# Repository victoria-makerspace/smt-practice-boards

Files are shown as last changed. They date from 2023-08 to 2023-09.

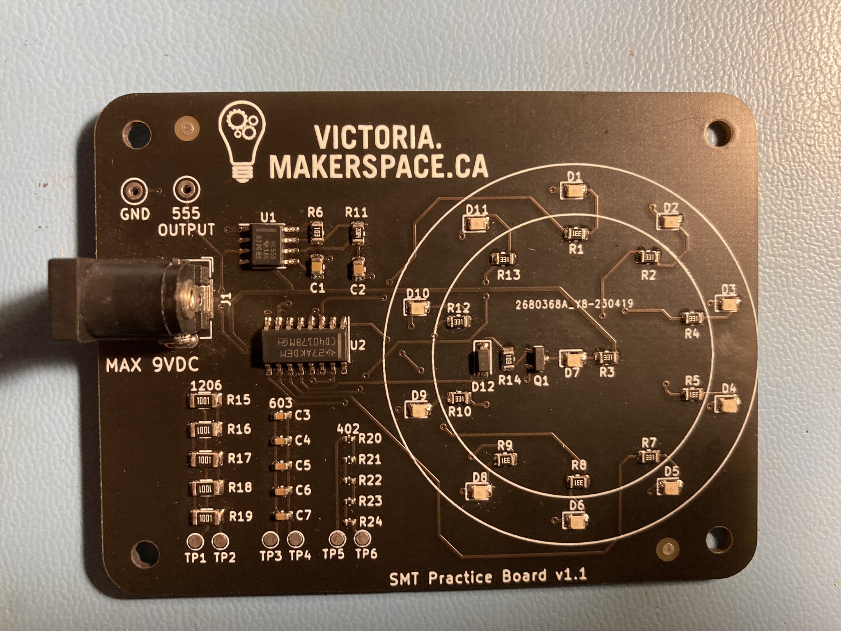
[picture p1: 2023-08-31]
board-rotating-leds/images/IMG_4738.jpeg

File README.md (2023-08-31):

# SMT Practice Boards

This repository contains Surface Mount Technology(SMT) board designs that are intended to be used for training purposes.  Every SMT practice board design provides the information:  

1. bom:  Bill of Materials, including DigiKey part references.
1. gerber: files used to order PCBs from suppliers such as PCBWay or JLCPCB.
1. images:  photos of the board
1. kicad:  KiCAD schematic and layout files.  Fiducials are included on the layouts to support automatic pick and place machines.
1. schematic:  PDF schematic 
1. stencil:  DXF and LightBurn format files used to make laser cut stencils.  Laser cut stencils can be created using 4 mil mylar. 

## Rotating LEDs Practice Board
The [Rotating LEDs practice board](https://github.com/victoria-makerspace/smt-practice-boards/tree/main/board-rotating-leds) is inspired from the [Gikfun SMT training board](https://gikfun.com/collections/frontpage/products/gikfun-diy-smd-smt-welding-practice-soldering-skill-training-board)



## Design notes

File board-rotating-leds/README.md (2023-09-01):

# Rotating LEDs Practice Board

Click on the image below to see the demo

Watch the video (https://www.youtube.com/embed/diBXtM5LNmg)

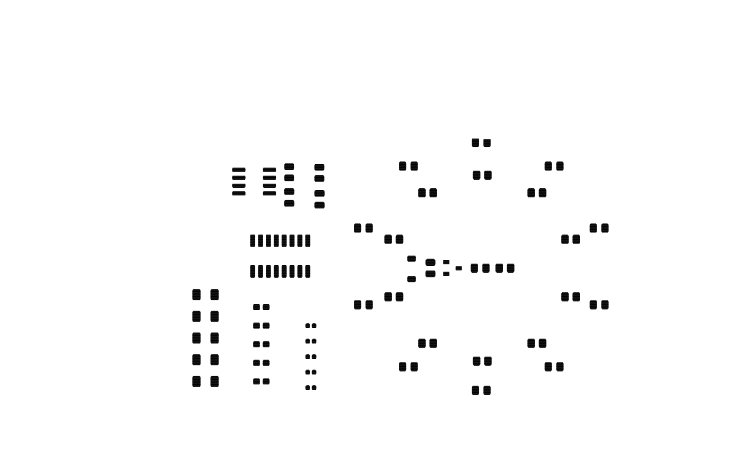
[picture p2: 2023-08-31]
board-rotating-leds/stencil/stencil-rotating-leds.png

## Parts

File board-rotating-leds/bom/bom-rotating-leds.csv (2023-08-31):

Description | Manufacturer Part Number | Digi-Key Part # | Quantity | Unit Price (USD)
DC POWER JACK, THRU HOLE, HORIZO | DCJ200-10-A-K1-K | 2073-DCJ200-10-A-K1-K-ND | 1 | $0.790
RES 330 OHM 5% 1/8W 0805 | RC0805JR-07330RL | 311-330ARCT-ND | 11 | $0.010
RES 1K OHM 1% 1/16W 0402 | WR04X1001FTL | 1292-WR04X1001FTLCT-ND | 5 | $0.004
TRANSISTOR, 25V 300MW 500MA 150MHZ 600MV@500 | S8050 | 4518-S8050CT-ND | 1 | $0.230
RES 2M OHM 1% 1/8W 0805 | RC0805FR-072ML | 311-2.00MCRCT-ND | 1 | $0.040
IC DECADE COUNTER 10-BIT 16SOIC | CD4017BM96 | 296-25940-1-ND | 1 | $0.630
RES 10K OHM 5% 1/8W 0805 | RC0805JR-0710KL | 311-10KARCT-ND | 2 | $0.030
DIODE GEN PURP 100V 150MA SOD123 | 1N4148W-TP | 1N4148WTPMSCT-ND | 1 | $0.100
RES 1K OHM 1% 1/2W 1206 | RNCP1206FTD1K00 | RNCP1206FTD1K00CT-ND | 5 | $0.090
IC OSC SGL TIMER 100KHZ 8-SOIC | NE555DR | 296-6501-1-ND | 1 | $0.520
RED LED, 2.0(L)X1.3(W)X0.8(H) MM | B1701USD-20D000114U1930 | 3147-B1701USD-20D000114U1930CT-ND | 10 | $0.100
BLUE LED, 2.0(L)X1.3(W)X0.8(H) MM | B1701NB--20D000114U1930 | 3147-B1701NB--20D000114U1930CT-ND | 1 | $0.110
CAP CER 0.1UF 50V X7R 0603 | C0603C104M5RAC7867 | 399-C0603C104M5RAC7867CT-ND | 5 | $0.010
CAP CER 0.1UF 50V X7R 0805 | C0805C104M5RAC7800 | 399-C0805C104M5RAC7800CT-ND | 2 | $0.070

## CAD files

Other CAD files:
board-rotating-leds/stencil/stencil-rotating-leds.dxf

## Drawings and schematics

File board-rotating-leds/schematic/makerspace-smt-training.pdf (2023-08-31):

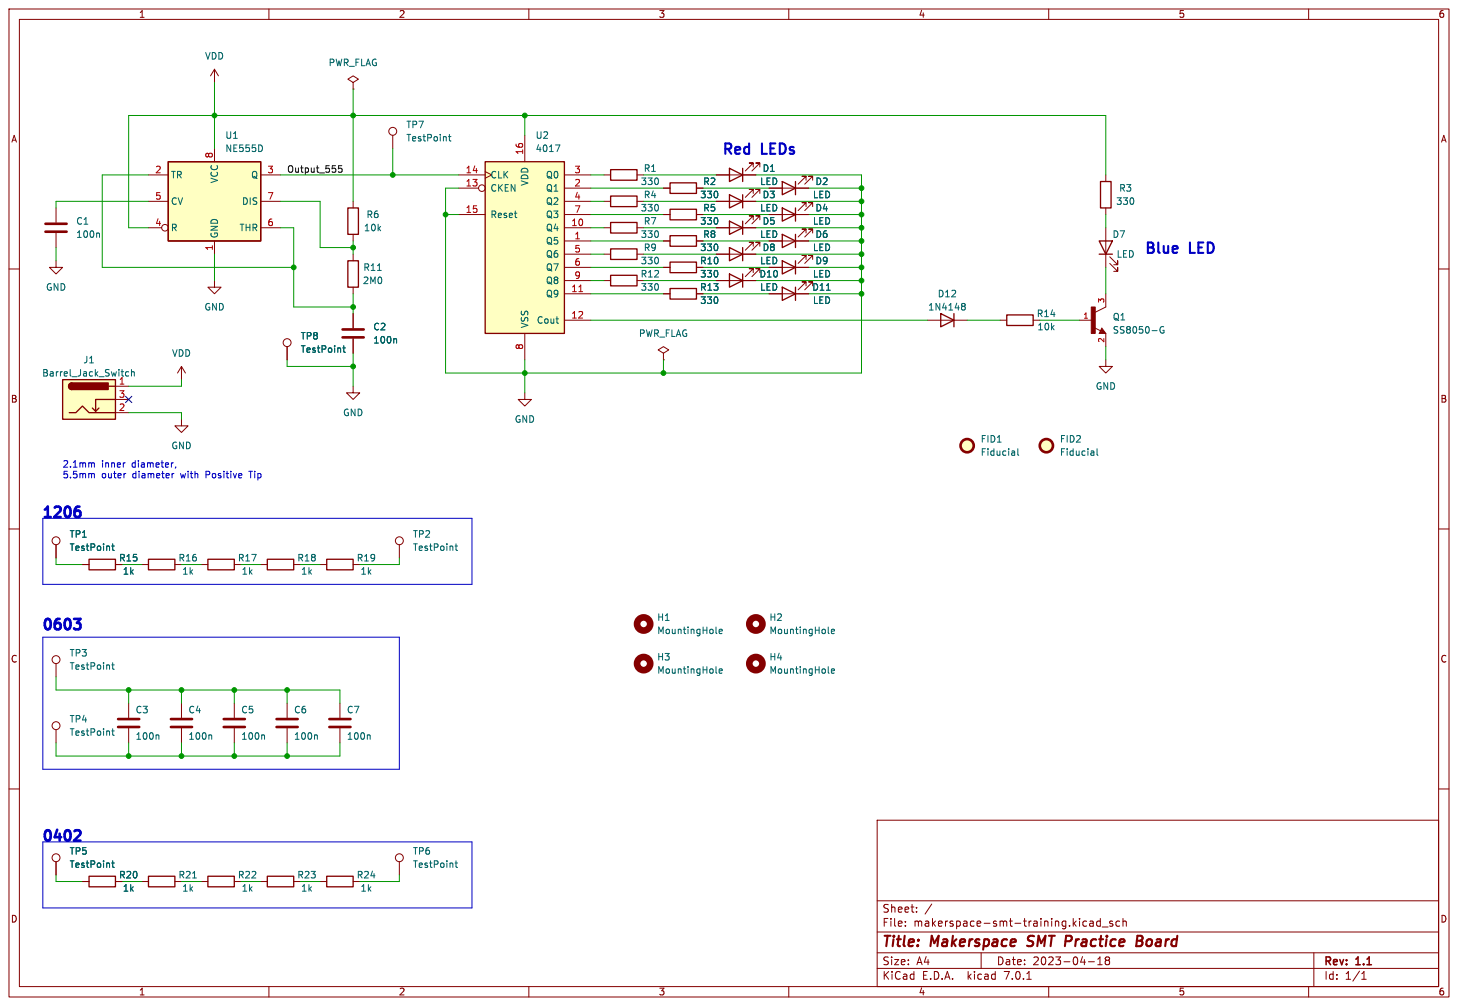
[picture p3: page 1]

File: makerspace-smt-training.kicad_sch Sheet: /
Id: 1/1 Title: Makerspace SMT Practice Board

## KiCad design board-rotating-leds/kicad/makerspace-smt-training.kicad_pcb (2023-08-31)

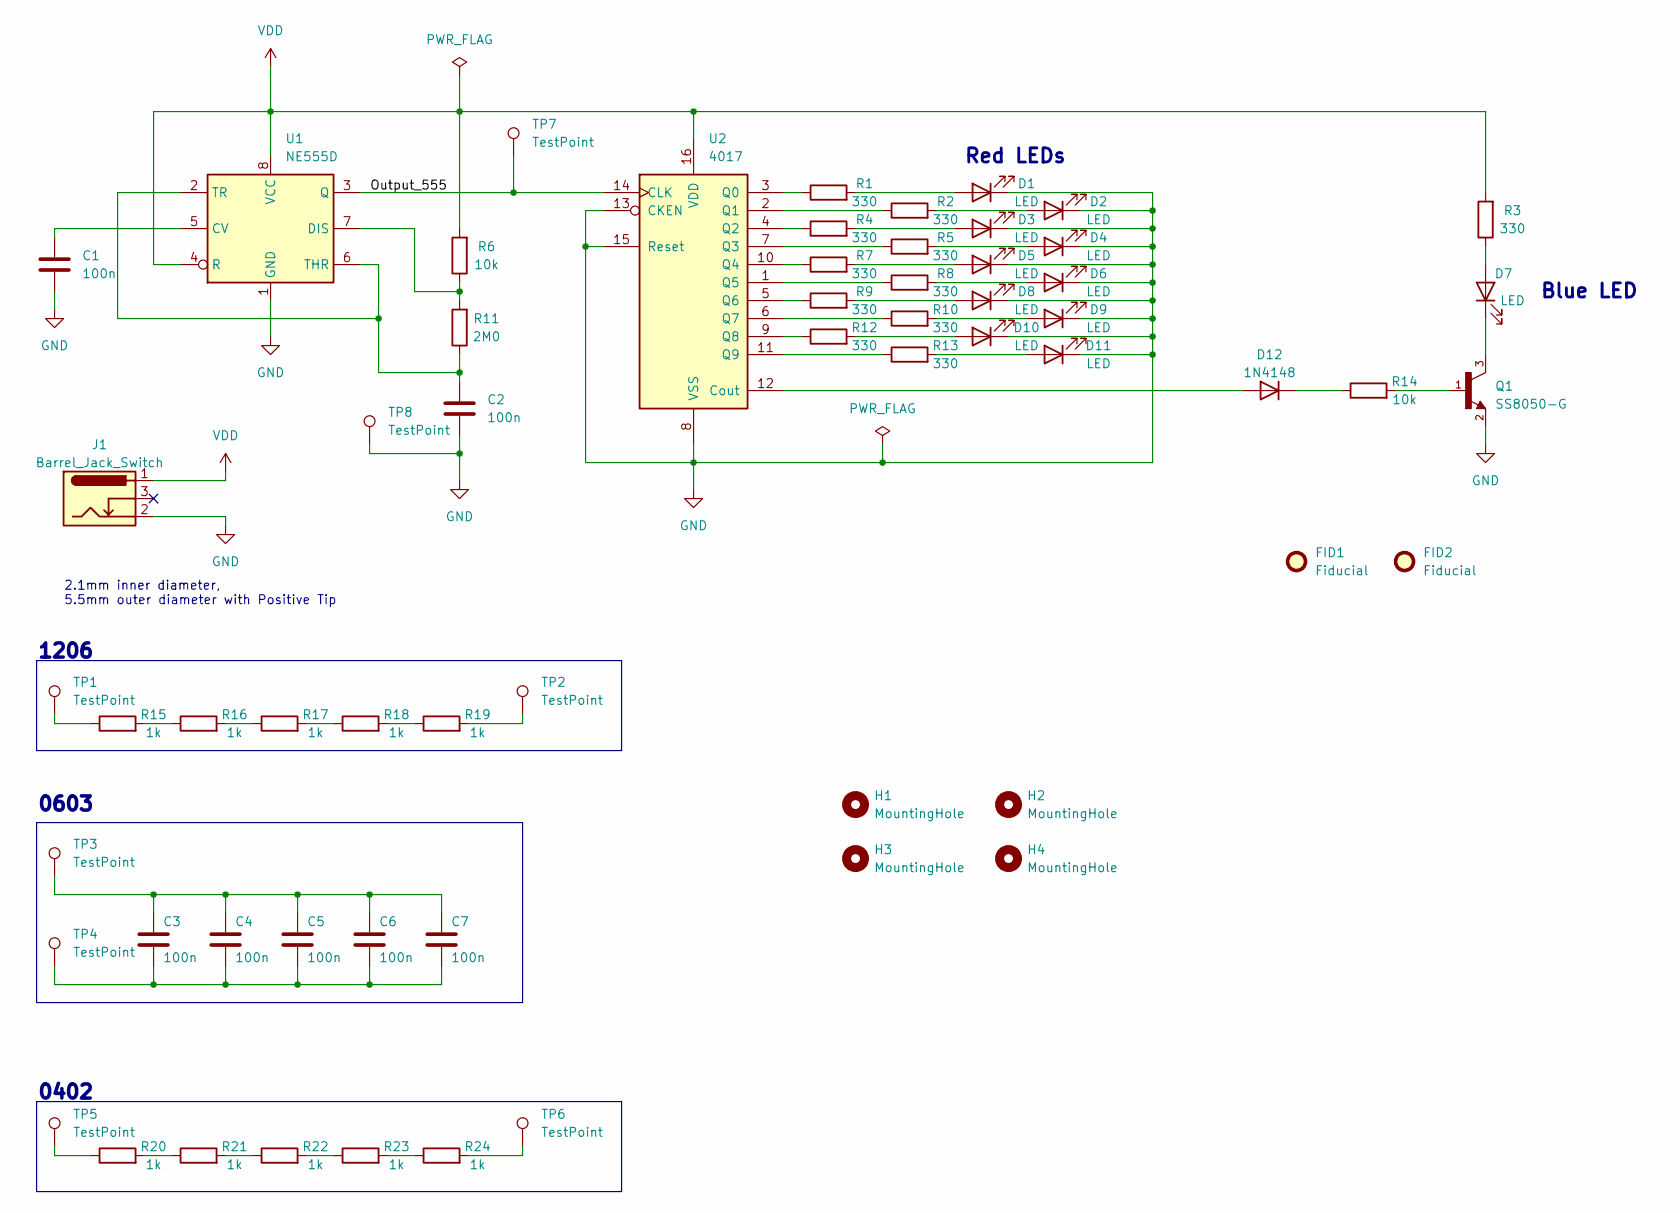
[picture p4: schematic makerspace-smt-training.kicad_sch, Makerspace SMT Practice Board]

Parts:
C1: 100n
C2: 100n; C_0805_2012Metric
C3, C4, C5, C6, C7: 100n; C_0603_1608Metric
D1, D2, D3, D4, D5, D6, D7, D8, D9, D10, D11: LED; LED_0805_2012Metric
D12: 1N4148; D_SOD-123
FID1, FID2: Fiducial; Fiducial_1.5mm_Mask3mm
H1, H2, H3, H4: MountingHole; MountingHole_3.2mm_M3
J1: Barrel_Jack_Switch; BarrelJack_GCT_DCJ200-10-A_Horizontal
Q1: SS8050-G; TRANS_SS8050-G; PARTREV A
R1, R2, R3, R4, R5, R7, R8, R9, R10, R12, R13: 330; R_0805_2012Metric
R6, R14: 10k; R_0805_2012Metric
R11: 2M0; R_0805_2012Metric
R15, R16, R17, R18, R19: 1k; R_1206_3216Metric
R20, R21, R22, R23, R24: 1k; R_0402_1005Metric
TP1, TP2, TP3, TP4, TP5, TP6: TestPoint; TestPoint_Pad_D1.5mm
TP7, TP8: TestPoint; TestPoint_Loop_D1.80mm_Drill1.0mm_Beaded
U1: NE555D; SOIC-8_3.9x4.9mm_P1.27mm
U2: 4017; SOIC-16_3.9x9.9mm_P1.27mm

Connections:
/Output_555: TP7.1, U1.3 (Q), U2.14 (CLK)
GND: C1.2, C2.2, D1.1 (K), D2.1 (K), D3.1 (K), D4.1 (K), D5.1 (K), D6.1 (K), D8.1 (K), D9.1 (K), D10.1 (K), D11.1 (K), J1.2, Q1.2, TP8.1, U1.1 (GND), U2.8 (VSS), U2.13 (CKEN), U2.15 (Reset)
unnamed: C3.1, C4.1, C5.1, C6.1, C7.1, TP3.1
unnamed: C3.2, C4.2, C5.2, C6.2, C7.2, TP4.1
unnamed: D1.2 (A), R1.2
unnamed: D2.2 (A), R2.2
unnamed: D3.2 (A), R4.2
unnamed: D4.2 (A), R5.2
unnamed: D5.2 (A), R7.2
unnamed: D6.2 (A), R8.2
unnamed: D7.2 (A), R3.1
unnamed: D7.1 (K), Q1.3
unnamed: D8.2 (A), R9.2
unnamed: D9.2 (A), R10.2
unnamed: D10.2 (A), R12.2
unnamed: D11.2 (A), R13.2
unnamed: D12.2 (A), U2.12 (Cout)
unnamed: D12.1 (K), R14.1
unnamed: Q1.1, R14.2
unnamed: R15.1, TP1.1
unnamed: R15.2, R16.1
unnamed: R16.2, R17.1
unnamed: R17.2, R18.1
unnamed: R18.2, R19.1
unnamed: R19.2, TP2.1
unnamed: R20.1, TP5.1
unnamed: R20.2, R21.1
unnamed: R21.2, R22.1
unnamed: R22.2, R23.1
unnamed: R23.2, R24.1
unnamed: R24.2, TP6.1
unnamed: C1.1, U1.5 (CV)
unnamed: R6.1, R11.2, U1.7 (DIS)
unnamed: C2.1, R11.1, U1.2 (TR), U1.6 (THR)
unnamed: R1.1, U2.3 (Q0)
unnamed: R2.1, U2.2 (Q1)
unnamed: R4.1, U2.4 (Q2)
unnamed: R5.1, U2.7 (Q3)
unnamed: R7.1, U2.10 (Q4)
unnamed: R8.1, U2.1 (Q5)
unnamed: R9.1, U2.5 (Q6)
unnamed: R10.1, U2.6 (Q7)
unnamed: R12.1, U2.9 (Q8)
unnamed: R13.1, U2.11 (Q9)
VDD: J1.1, R3.2, R6.2, U1.4 (R), U1.8 (VCC), U2.16 (VDD)

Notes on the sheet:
0603
2.1mm inner diameter, 5.5mm outer diameter with Positive Tip
1206
Blue LED
0402
Red LEDs

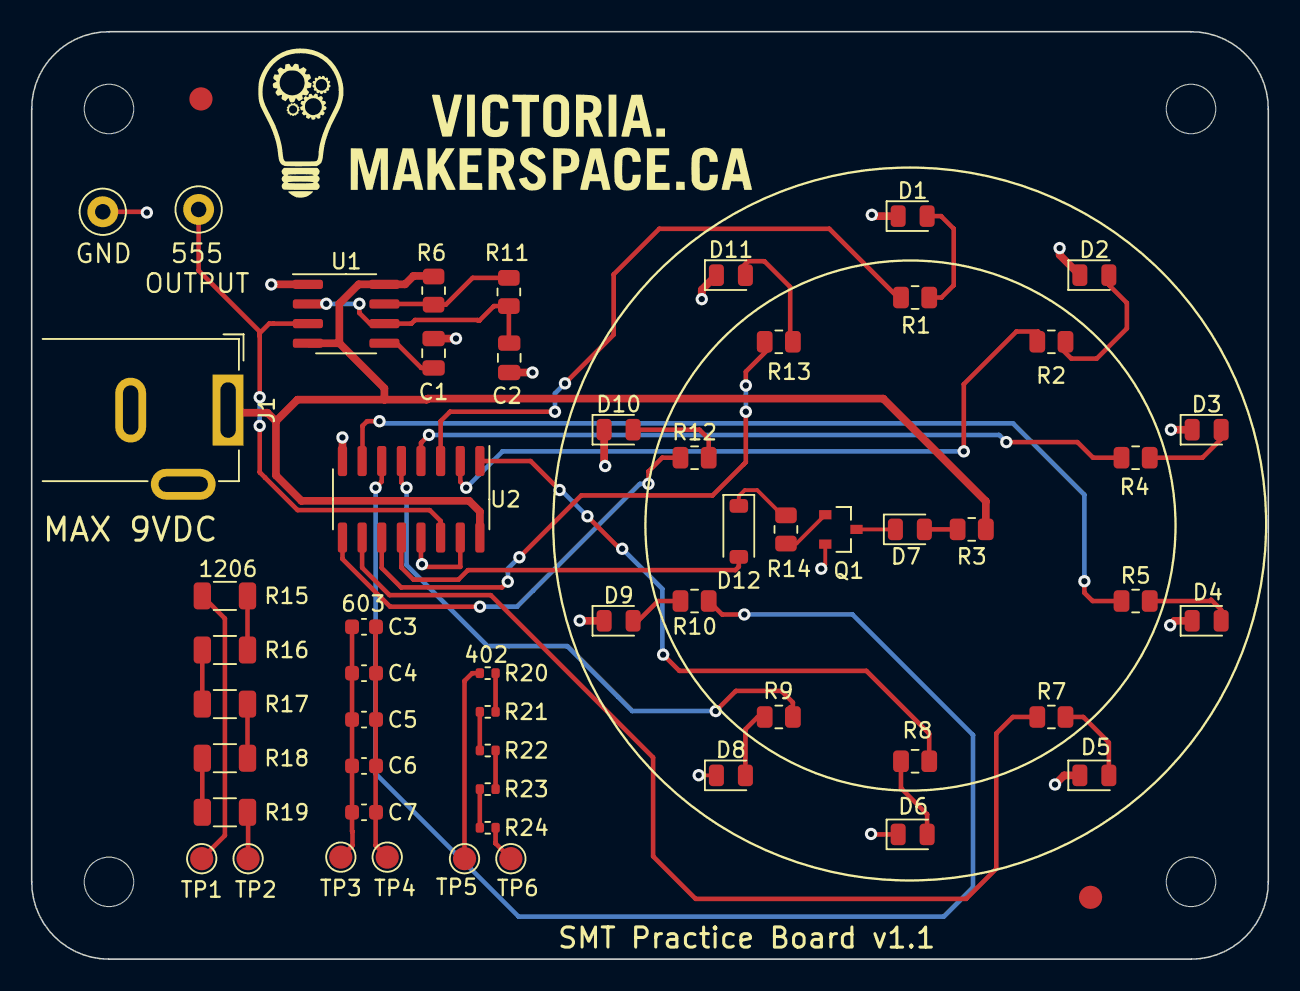
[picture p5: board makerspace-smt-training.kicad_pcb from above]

Board: 2 copper layers, 80.0 x 60.0 mm, 61 parts (0 on the bottom side), 45 nets.

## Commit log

2023-08-31 version 1.1 of Rotating LED SMT practice board
    [makerspace-smt-training-B_Cu.gbr, makerspace-smt-training-B_Mask.gbr, makerspace-smt-training-Edge_Cuts.gbr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]
2023-08-31 Update README.md
    added video showing the board in action
2023-08-31 added BOM
    [bom-rotating-leds.csv]
